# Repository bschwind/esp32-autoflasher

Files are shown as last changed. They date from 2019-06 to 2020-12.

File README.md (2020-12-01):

# esp32-autoflasher

KiCad PCB based on the CP2102N USB-UART serial converter. This implements the "auto reset" circuits of most ESP32 dev boards. You can run things like esp-idf's `make flash` or flash code from the Arduino IDE without having to hold down any buttons.

Connect `EN`, `RX`, `TX`, `IO0`, and `GND` to their respective pins on the ESP32 (don't forget to swap the `RX` and `TX` pins!) and make sure you have the Silicon Labs CP210x driver installed on your OS.

You can order this PCB on [OshPark](https://oshpark.com/shared_projects/q04gDLKl)

## Required Parts

(All resistors and capacitors are size 1608 metric)

| Label | Description |
| --- | --- |
| U1 | CP2102N |
| R1 | 1 kOhm |
| R2 | 10 kOhm |
| R3 | 22.1 kOhm |
| R4 | 10 kOhm |
| R5 | 47.5 kOhm |
| C1 | 4.7 uF |
| C2 | 0.1 uF |
| C3 | 4.7 uF |
| C4 | 0.1 uF |
| Q1 | MMBT2222L transistor (SOT-23 package) |
| Q2 | MMBT2222L transistor (SOT-23 package) |

## Images

### Schematic
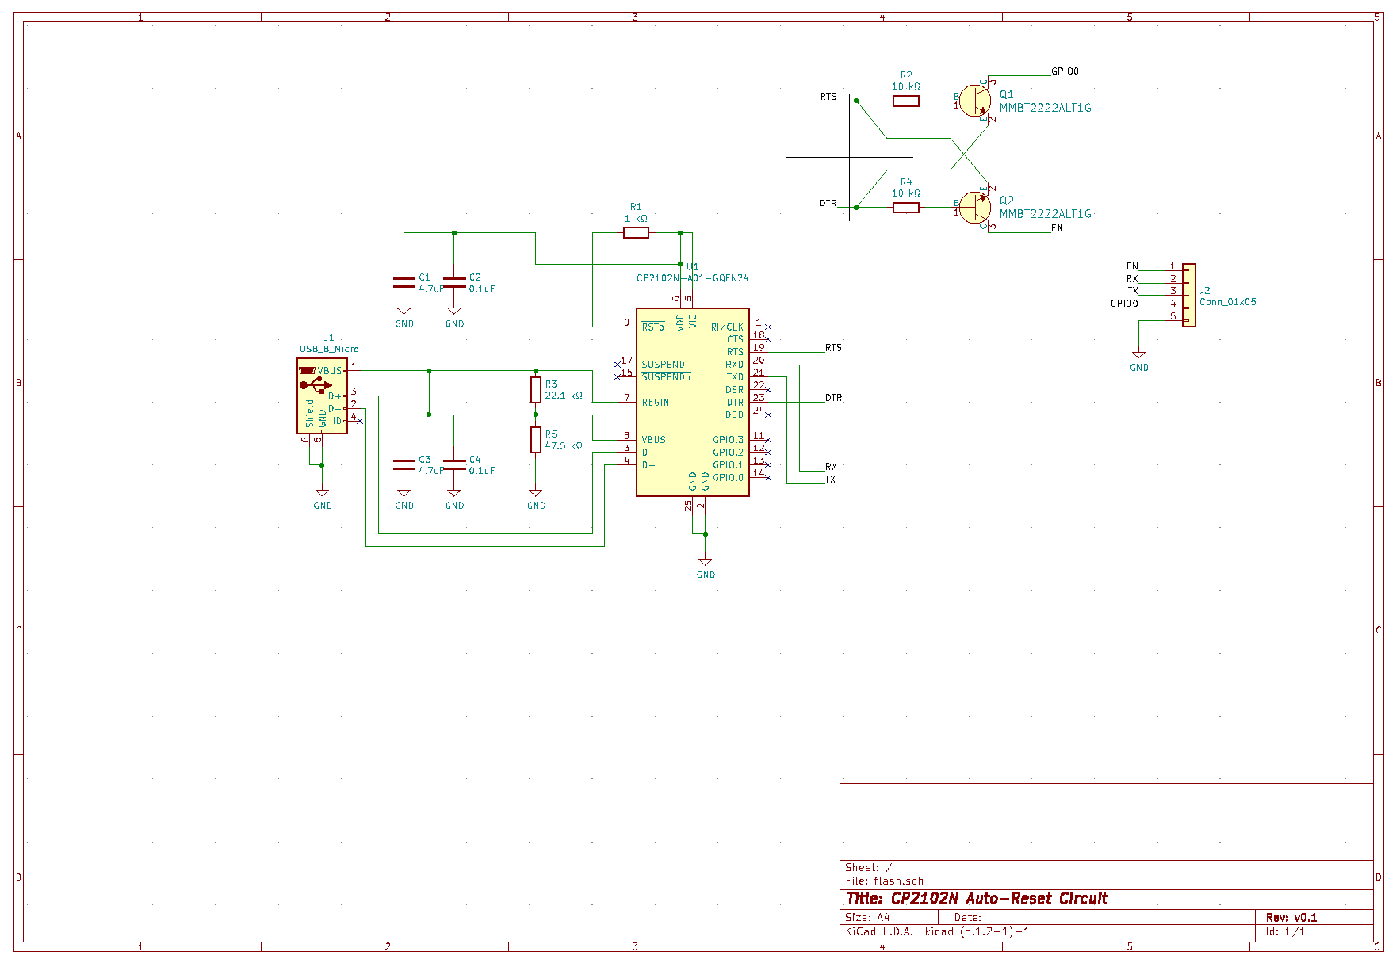
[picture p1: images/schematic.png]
schematic


### PCB Layout
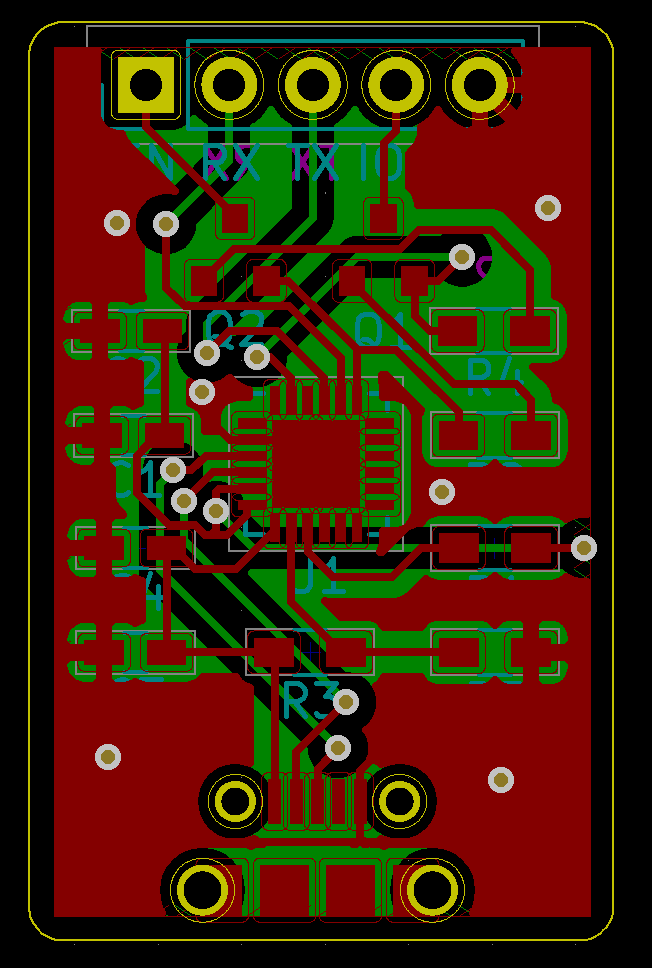
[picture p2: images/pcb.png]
pcb


### Assembled
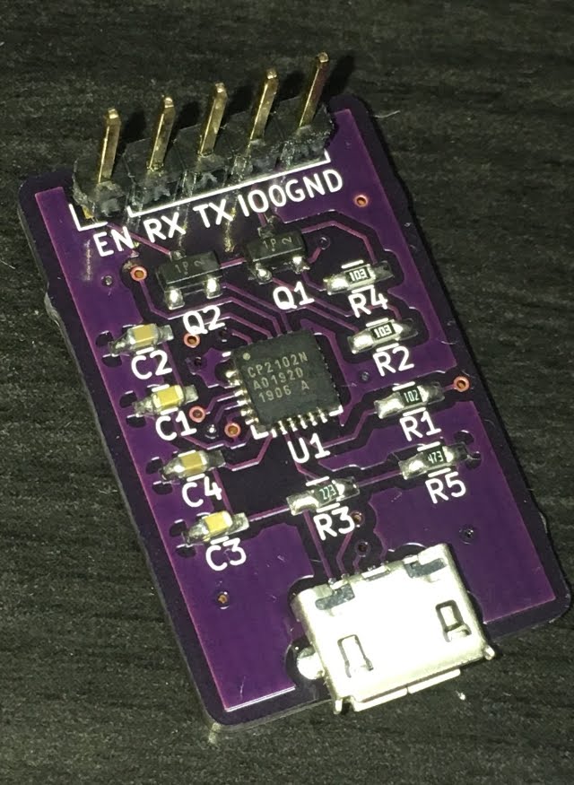
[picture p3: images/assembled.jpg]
assembled


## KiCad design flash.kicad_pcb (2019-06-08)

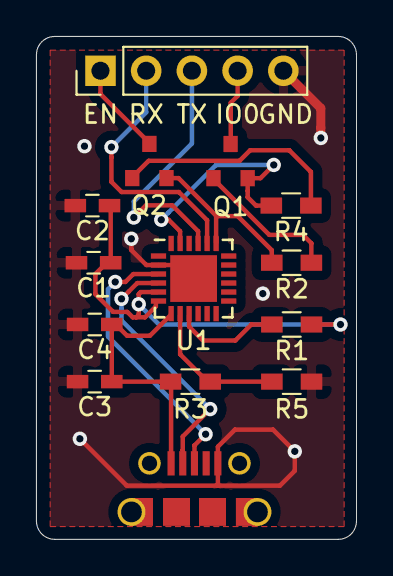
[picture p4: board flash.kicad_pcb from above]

Board: 2 copper layers, 17.8 x 27.9 mm, 14 parts (0 on the bottom side), 15 nets.

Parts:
C1, C3: 4.7uF; C_0603_HandSoldering
C2, C4: 0.1uF; C_0603_HandSoldering
J1: USB_B_Micro; 10118194-0001lf-circle
J2: Conn_01x05; Pin_Header_Straight_1x05_Pitch2.54mm
Q1, Q2: MMBT2222ALT1G; mmbt2222alt1g
R1: 1 kΩ; R_0603_HandSoldering
R2, R4: 10 kΩ; R_0603_HandSoldering
R3: 22.1 kΩ; R_0603_HandSoldering
R5: 47.5 kΩ; R_0603_HandSoldering
U1: CP2102N-A01-GQFN24; QFN-24-1EP_4x4mm_Pitch0.5mm

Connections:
/DTR: Q1.2, R4.2, U1.23
/EN: J2.1, Q2.3
/GPIO0: J2.4, Q1.3
/RTS: Q2.2, R2.2, U1.19
/RX: J2.2, U1.20
/TX: J2.3, U1.21
GND: C1.2, C2.2, C3.2, C4.2, J1.5, J2.5, R5.2, U1.2, U1.25
unnamed: C1.1, C2.1, R1.1, U1.5, U1.6
unnamed: C3.1, C4.1, J1.1, R3.1, U1.7
unnamed: J1.2, U1.4
unnamed: J1.3, U1.3
unnamed: Q1.1, R2.1
unnamed: Q2.1, R4.1
unnamed: R1.2, U1.9
unnamed: R3.2, R5.1, U1.8

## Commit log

2019-05-06 Add schematic
    [flash.kicad_pcb, flash.sch]
2019-05-08 Add first iteration of PCB design
    [flash.kicad_pcb, flash.sch]
2019-05-11 Finish PCB
    [flash.kicad_pcb, flash.sch]
2019-06-08 Swap RX/TX pins, fix DTR/RTS transistor wiring
    [flash.kicad_pcb, flash.sch]
2019-06-08 Swap RX/TX silkscreen labels
    [flash.kicad_pcb]
2019-06-08 Adjust GND via from header pin
    [flash.kicad_pcb]
2019-10-18 Add board images and .gitignore
